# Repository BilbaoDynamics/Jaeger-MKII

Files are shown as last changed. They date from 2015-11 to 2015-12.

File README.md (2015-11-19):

# Jaeger MKII

Jaeger photo

## What's this?

An open source Micro rover robot

## License

GPL license or Creative Commons Attribution-shareAlike (Copyleft)

![license] (http://es.creativecommons.org/blog/wp-content/uploads/2013/04/by-sa_petit.png)

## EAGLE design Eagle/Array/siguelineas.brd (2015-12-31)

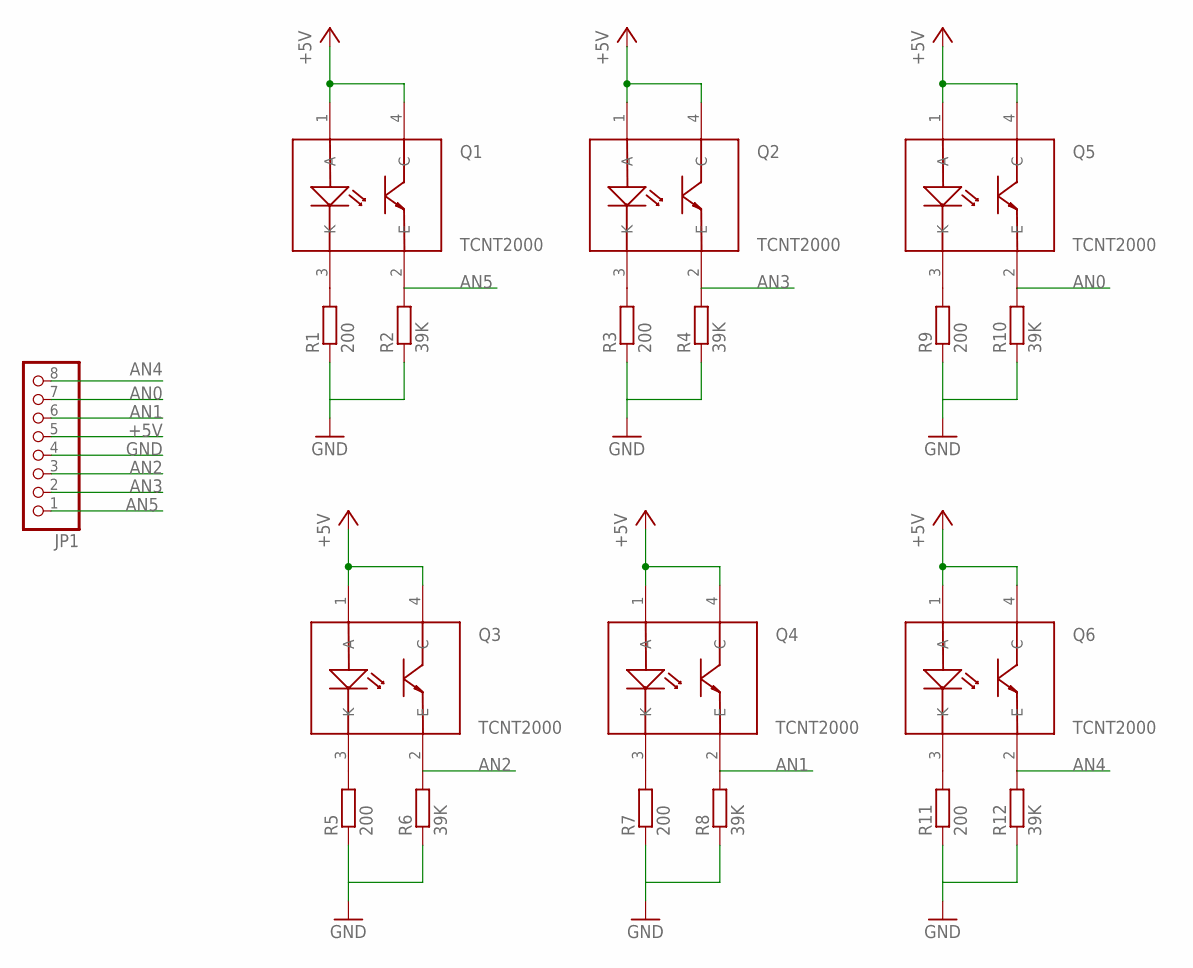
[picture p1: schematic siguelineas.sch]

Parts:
JP1: PINHD-1X8; 1X08
Q1, Q2, Q3, Q4, Q5, Q6: TCNT2000; SMD
R1, R3, R5, R7, R9, R11: 200; R0805
R2, R4, R6, R8, R10, R12: 39K; R0805

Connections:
+5V: JP1.5, Q1.1 (A), Q1.4 (C), Q2.1 (A), Q2.4 (C), Q3.1 (A), Q3.4 (C), Q4.1 (A), Q4.4 (C), Q5.1 (A), Q5.4 (C), Q6.1 (A), Q6.4 (C)
AN0: JP1.7, Q5.2 (E), R10.2
AN1: JP1.6, Q4.2 (E), R8.2
AN2: JP1.3, Q3.2 (E), R6.2
AN3: JP1.2, Q2.2 (E), R4.2
AN4: JP1.8, Q6.2 (E), R12.2
AN5: JP1.1, Q1.2 (E), R2.2
GND: JP1.4, R1.1, R2.1, R3.1, R4.1, R5.1, R6.1, R7.1, R8.1, R9.1, R10.1, R11.1, R12.1
unnamed: Q1.3 (K), R1.2
unnamed: Q2.3 (K), R3.2
unnamed: Q3.3 (K), R5.2
unnamed: Q4.3 (K), R7.2
unnamed: Q5.3 (K), R9.2
unnamed: Q6.3 (K), R11.2

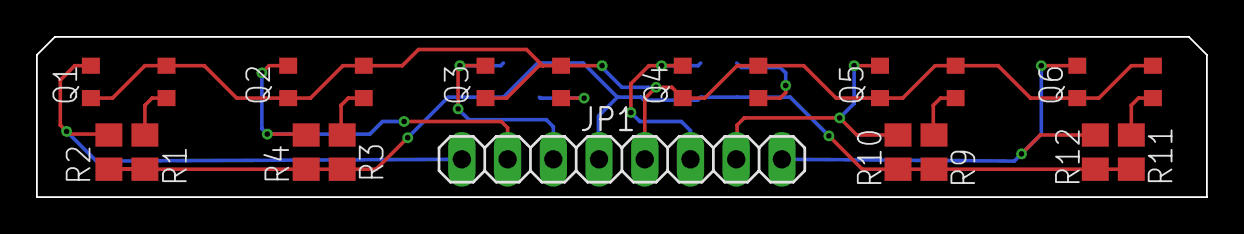
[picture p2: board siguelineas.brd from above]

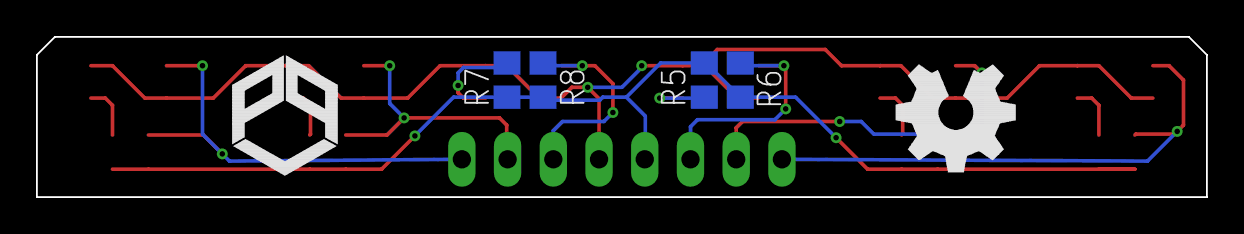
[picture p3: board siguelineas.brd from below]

Board: 2 copper layers, 65.0 x 8.9 mm, 19 parts (4 on the bottom side), 14 nets.

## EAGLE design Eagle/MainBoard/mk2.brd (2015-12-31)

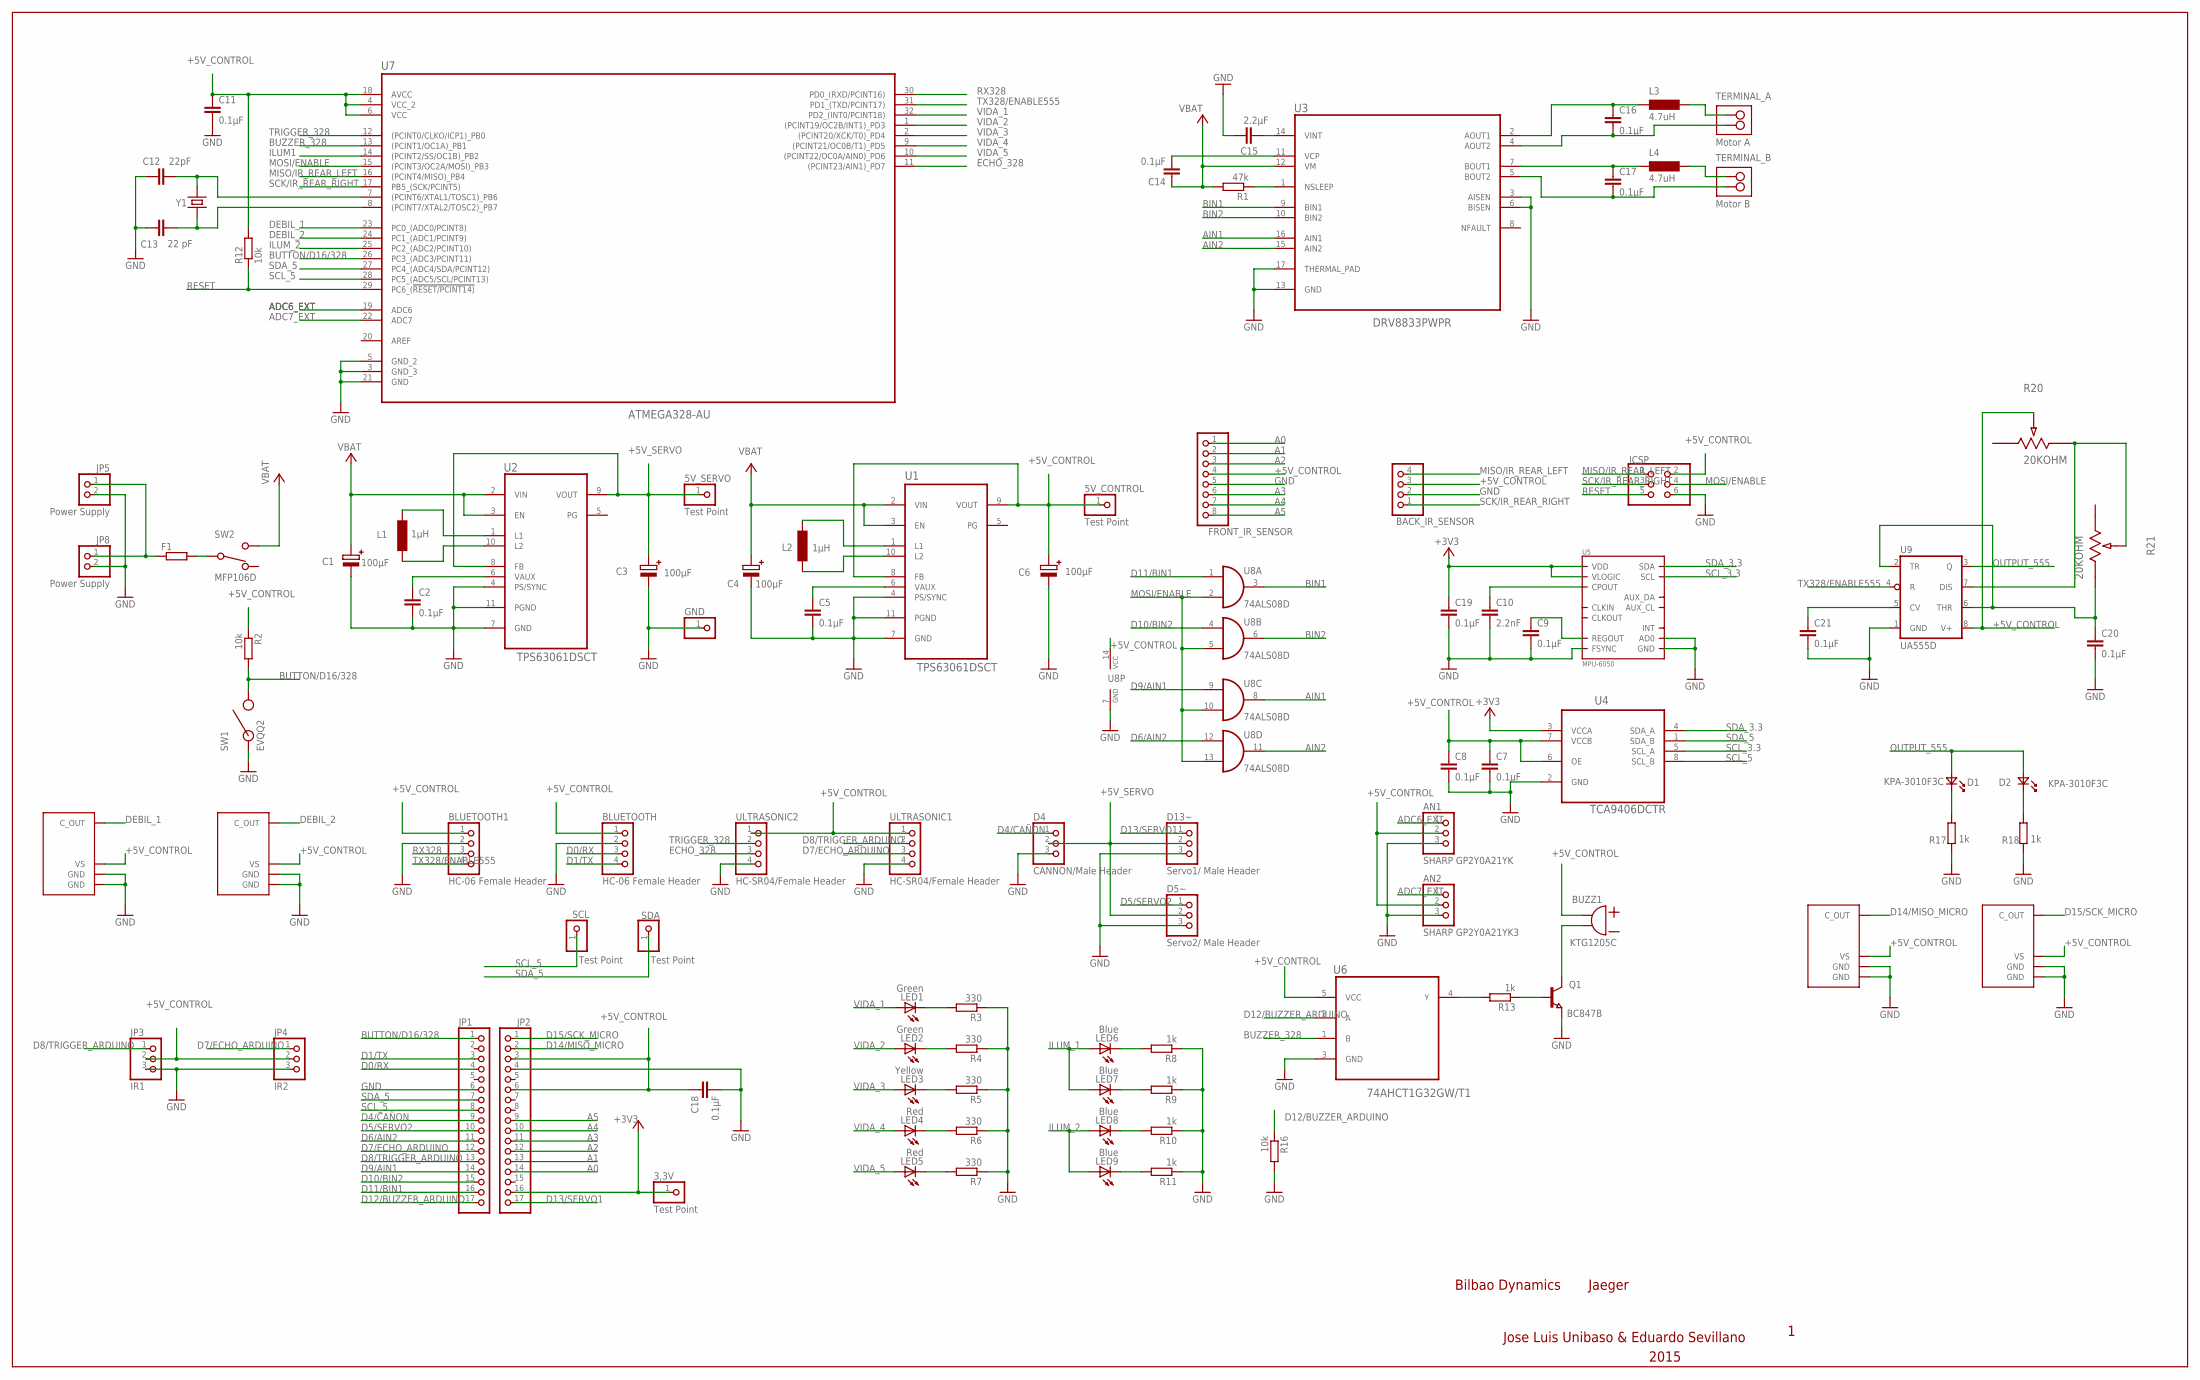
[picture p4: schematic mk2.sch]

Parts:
3,3V, 5V_CONTROL, 5V_SERVO: Test Point; 1X01
AN1: SHARP GP2Y0A21YK; 1X03
AN2: SHARP GP2Y0A21YK3; 1X03
BACK_IR_SENSOR: PINHD-1X4; 1X04
BLUETOOTH, BLUETOOTH1: HC-06 Female Header; 1X04
BUZZ1: KTG1205C
C1, C3, C4, C6: 100µF; EDK107M016A9G
C2, C5, C11: 0.1µF; C0805K
C7, C8, C9, C14, C16, C17, C18, C19, C20, C21: 0.1µF; C0805
C10: 2.2nF; C0805
C12: 22pF; C0805K
C13: 22 pF; C0805K
C15: 2.2µF; C0805
D1, D2: KPA-3010F3C
D4: CANNON/Male Header; 1X03
D5~: Servo2/ Male Header; 1X03
D13~: Servo1/ Male Header; 1X03
F1: R-EU_R1206; R1206
FRONT_IR_SENSOR: PINHD-1X8; 1X08
GND: PINHD-1X1; 1X01
ICSP: PINHD-2X3; 2X03
IR_REC1, IR_REC2, IR_REC3, IR_REC4: TSMP77000TR
JP1, JP2: PINHD-1X17; 1X17
JP3: IR1; 1X03
JP4: IR2; 1X03
JP5, JP8: Power Supply; 1X02
L1, L2: 1µH; MCSDRH73B
L3, L4: 4.7uH; SRN4012T-4R7M
LED1, LED2: Green; SML0805
LED3: Yellow; SML0805
LED4, LED5: Red; SML0805
LED6, LED7, LED8, LED9: Blue; SML0805
Q1: BC847B; SOT23
R1: 47k; R0805
R2, R12, R16: 10k; R0805
R3, R4, R5, R6, R7: 330; R0805
R8, R9, R10, R11, R13, R17, R18: 1k; R0805
R20, R21: 20KOHM; POT_EVM2N
SCL: Test Point; 1X01
SDA: Test Point; 1X01
SW1: EVQQ2
SW2: MFP106D
TERMINAL_A: Motor A; CTB30512BK
TERMINAL_B: Motor B; CTB30512BK
U1, U2: TPS63061DSCT; SON50P300X300X80-11N
U3: DRV8833PWPR; SOP65P640X120-17N
U4: TCA9406DCTR; SOP65P400X130-8N
U5: MPU-6050; QFN.24.4X4
U6: 74AHCT1G32GW/T1; SOT65P210X110-5N
U7: ATMEGA328-AU; QFP80P900X900X120-32N
U8: 74ALS08D; SO14
U9: UA555D; SO08
ULTRASONIC1, ULTRASONIC2: HC-SR04/Female Header; 1X04
Y1: E3SB16.0000F09G11AE; E3SB16.0000F09G11A

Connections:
+3V3: 3,3V.1, JP2.16, U4.3 (VCCA)
+5V_CONTROL: 5V_CONTROL.1, AN1.2, AN2.2, BACK_IR_SENSOR.3, BLUETOOTH.1, BLUETOOTH1.1, BUZZ1.+, C6.1, C7.1, C8.1, C11.1, C18.1, FRONT_IR_SENSOR.4, ICSP.2, IR_REC1.2 (VS), IR_REC2.2 (VS), IR_REC3.2 (VS), IR_REC4.2 (VS), JP2.3, JP2.6, JP3.2, JP4.2, R2.1, R12.2, R20.2, U1.8 (FB), U1.9 (VOUT), U4.6 (OE), U4.7 (VCCB), U6.5 (VCC), U7.4 (VCC_2), U7.6 (VCC), U7.18 (AVCC), U8.14 (VCC), U9.8 (V+), ULTRASONIC1.1, ULTRASONIC2.1
+5V_SERVO: 5V_SERVO.1, C3.1, D4.2, D5~.2, D13~.2, U2.8 (FB), U2.9 (VOUT)
A0: FRONT_IR_SENSOR.1, JP2.14
A1: FRONT_IR_SENSOR.2, JP2.13
A2: FRONT_IR_SENSOR.3, JP2.12
A3: FRONT_IR_SENSOR.6, JP2.11
A4: FRONT_IR_SENSOR.7, JP2.10
A5: FRONT_IR_SENSOR.8, JP2.9
ADC6_EXT: AN1.1, U7.19 (ADC6)
ADC7_EXT: AN2.1, U7.22 (ADC7)
AIN1: U3.16 (AIN1), U8.8 (O)
AIN2: U3.15 (AIN2), U8.11 (O)
AM1: L3.P$2, TERMINAL_A.1
BIN1: U3.9 (BIN1), U8.3 (O)
BIN2: U3.10 (BIN2), U8.6 (O)
BM1: L4.P$2, TERMINAL_B.1
BUTTON/D16/328: JP1.1, R2.2, SW1.P$1, SW1.P$4, U7.26 (PC3_(ADC3/PCINT11))
BUZZER_328: U6.1 (B), U7.13 ((PCINT1/OC1A)_PB1)
C14: C13.2, U7.8 ((PCINT7/XTAL2/TOSC2)_PB7), Y1.1
D0/RX: BLUETOOTH.3, JP1.4
D1/TX: BLUETOOTH.4, JP1.3
D2: D2.C, R18.1
D4/CAÑON: D4.1, JP1.9
D5/SERVO2: D5~.1, JP1.10
D6/AIN2: JP1.11, U8.12 (I0)
D7/ECHO_ARDUINO: JP1.12, JP4.1, ULTRASONIC1.3
D8/TRIGGER_ARDUINO: JP1.13, JP3.1, ULTRASONIC1.2
D9/AIN1: JP1.14, U8.9 (I0)
D10/BIN2: JP1.15, U8.4 (I0)
D11/BIN1: JP1.16, U8.1 (I0)
D12/BUZZER_ARDUINO: JP1.17, R16.1, U6.2 (A)
D13/SERVO1: D13~.1, JP2.17
D14/MISO_MICRO: IR_REC1.3 (C_OUT), JP2.2
D15/SCK_MICRO: IR_REC2.3 (C_OUT), JP2.1
DEBIL_1: IR_REC3.3 (C_OUT), U7.23 (PC0_(ADC0/PCINT8))
DEBIL_2: IR_REC4.3 (C_OUT), U7.24 (PC1_(ADC1/PCINT9))
ECHO_328: U7.11 ((PCINT23/AIN1)_PD7), ULTRASONIC2.3
GND: AN1.3, AN2.3, BACK_IR_SENSOR.2, BLUETOOTH.2, BLUETOOTH1.2, C1.2, C2.2, C3.2, C4.2, C5.2, C6.2, C7.2, C8.2, C9.2, C10.2, C11.2, C12.1, C13.1, C15.1, C18.2, C19.2, C20.2, C21.2, D4.3, D5~.3, D13~.3, FRONT_IR_SENSOR.5, GND.1, ICSP.6, IR_REC1.1 (GND), IR_REC1.4 (GND), IR_REC2.1 (GND), IR_REC2.4 (GND), IR_REC3.1 (GND), IR_REC3.4 (GND), IR_REC4.1 (GND), IR_REC4.4 (GND), JP1.6, JP2.4, JP3.3, JP4.3, JP5.2, JP8.2, Q1.2 (E), R3.1, R4.1, R5.1, R6.1, R7.1, R8.1, R9.1, R10.1, R11.1, R16.2, R17.2, R18.2, SW1.P$2, SW1.P$3, U1.4 (PS/SYNC), U1.7 (GND), U1.11 (PGND), U2.4 (PS/SYNC), U2.7 (GND), U2.11 (PGND), U3.3 (AISEN), U3.6 (BISEN), U3.13 (GND), U3.17 (THERMAL_PAD), U4.2 (GND), U5.9 (AD0), U5.11 (FSYNC), U5.18 (GND), U6.3 (GND), U7.3 (GND_3), U7.5 (GND_2), U7.21 (GND), U8.7 (GND), U9.1 (GND), ULTRASONIC1.4, ULTRASONIC2.4
ILUM1: U7.14 ((PCINT2/SS/OC1B)_PB2)
ILUM_1: LED6.A, LED7.A
ILUM_2: LED8.A, LED9.A, U7.25 (PC2_(ADC2/PCINT10))
LED4: LED4.C, R6.2
MISO/IR_REAR_LEFT: BACK_IR_SENSOR.4, ICSP.1, U7.16 ((PCINT4/MISO)_PB4)
MOSI/ENABLE: ICSP.4, U7.15 ((PCINT3/OC2A/MOSI)_PB3), U8.2 (I1), U8.5 (I1), U8.10 (I1), U8.13 (I1)
unnamed: C16.1, L3.P$1, U3.2 (AOUT1)
unnamed: C16.2, TERMINAL_A.2, U3.4 (AOUT2)
unnamed: C17.1, L4.P$1, U3.7 (BOUT1)
unnamed: C17.2, TERMINAL_B.2, U3.5 (BOUT2)
unnamed: C19.1, U5.8 (VLOGIC), U5.13 (VDD)
unnamed: F1.1, JP5.1, JP8.1
unnamed: R1.1, U3.1 (NSLEEP)
unnamed: C14.2, U3.11 (VCP)
unnamed: L2.2, U1.1 (L1)
unnamed: C2.1, U2.6 (VAUX)
unnamed: L2.1, U1.10 (L2)
unnamed: R13.2, U6.4 (Y)
unnamed: Q1.1 (B), R13.1
unnamed: L1.2, U2.1 (L1)
unnamed: L1.1, U2.10 (L2)
unnamed: BUZZ1.-, Q1.3 (C)
unnamed: C5.1, U1.6 (VAUX)
unnamed: LED1.C, R3.2
unnamed: LED2.C, R4.2
unnamed: LED3.C, R5.2
unnamed: LED8.C, R10.2
unnamed: D1.C, R17.1
unnamed: LED5.C, R7.2
unnamed: C15.2, U3.14 (VINT)
unnamed: C12.2, U7.7 ((PCINT6/XTAL1/TOSC1)_PB6), Y1.2
unnamed: C20.1, R21.3, U9.2 (TR), U9.6 (THR)
unnamed: LED6.C, R8.2
unnamed: LED7.C, R9.2
unnamed: LED9.C, R11.2
unnamed: C10.1, U5.20 (CPOUT)
unnamed: C9.1, U5.10 (REGOUT)
unnamed: R20.3, R21.2, U9.7 (DIS)
unnamed: F1.2, SW2.COM
unnamed: C21.1, U9.5 (CV)
OUTPUT_555: D1.A, D2.A, U9.3 (Q)
RESET: ICSP.5, R12.1, U7.29 (PC6_(!RESET/PCINT14))
RX328: BLUETOOTH1.3, U7.30 (PD0_(RXD/PCINT16))
SCK/IR_REAR_RIGHT: BACK_IR_SENSOR.1, ICSP.3, U7.17 (PB5_(SCK/PCINT5))
SCL_3.3: U4.5 (SCL_A), U5.23 (SCL)
SCL_5: JP1.8, SCL.1, U4.8 (SCL_B), U7.28 (PC5_(ADC5/SCL/PCINT13))
SDA_3.3: U4.4 (SDA_A), U5.24 (SDA)
SDA_5: JP1.7, SDA.1, U4.1 (SDA_B), U7.27 (PC4_(ADC4/SDA/PCINT12))
TRIGGER_328: U7.12 ((PCINT0/CLKO/ICP1)_PB0), ULTRASONIC2.2
TX328/ENABLE555: BLUETOOTH1.4, U7.31 (PD1_(TXD/PCINT17)), U9.4 (R)
VBAT: C1.1, C4.1, C14.1, R1.2, SW2.2, U1.2 (VIN), U1.3 (EN), U2.2 (VIN), U2.3 (EN), U3.12 (VM)
VIDA_1: LED1.A, U7.32 (PD2_(INT0/PCINT18))
VIDA_2: LED2.A, U7.1 ((PCINT19/OC2B/INT1)_PD3)
VIDA_3: LED3.A, U7.2 ((PCINT20/XCK/T0)_PD4)
VIDA_4: LED4.A, U7.9 ((PCINT21/OC0B/T1)_PD5)
VIDA_5: LED5.A, U7.10 ((PCINT22/OC0A/AIN0)_PD6)

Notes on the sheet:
Bilbao Dynamics
Jaeger
Jose Luis Unibaso & Eduardo Sevillano
2015

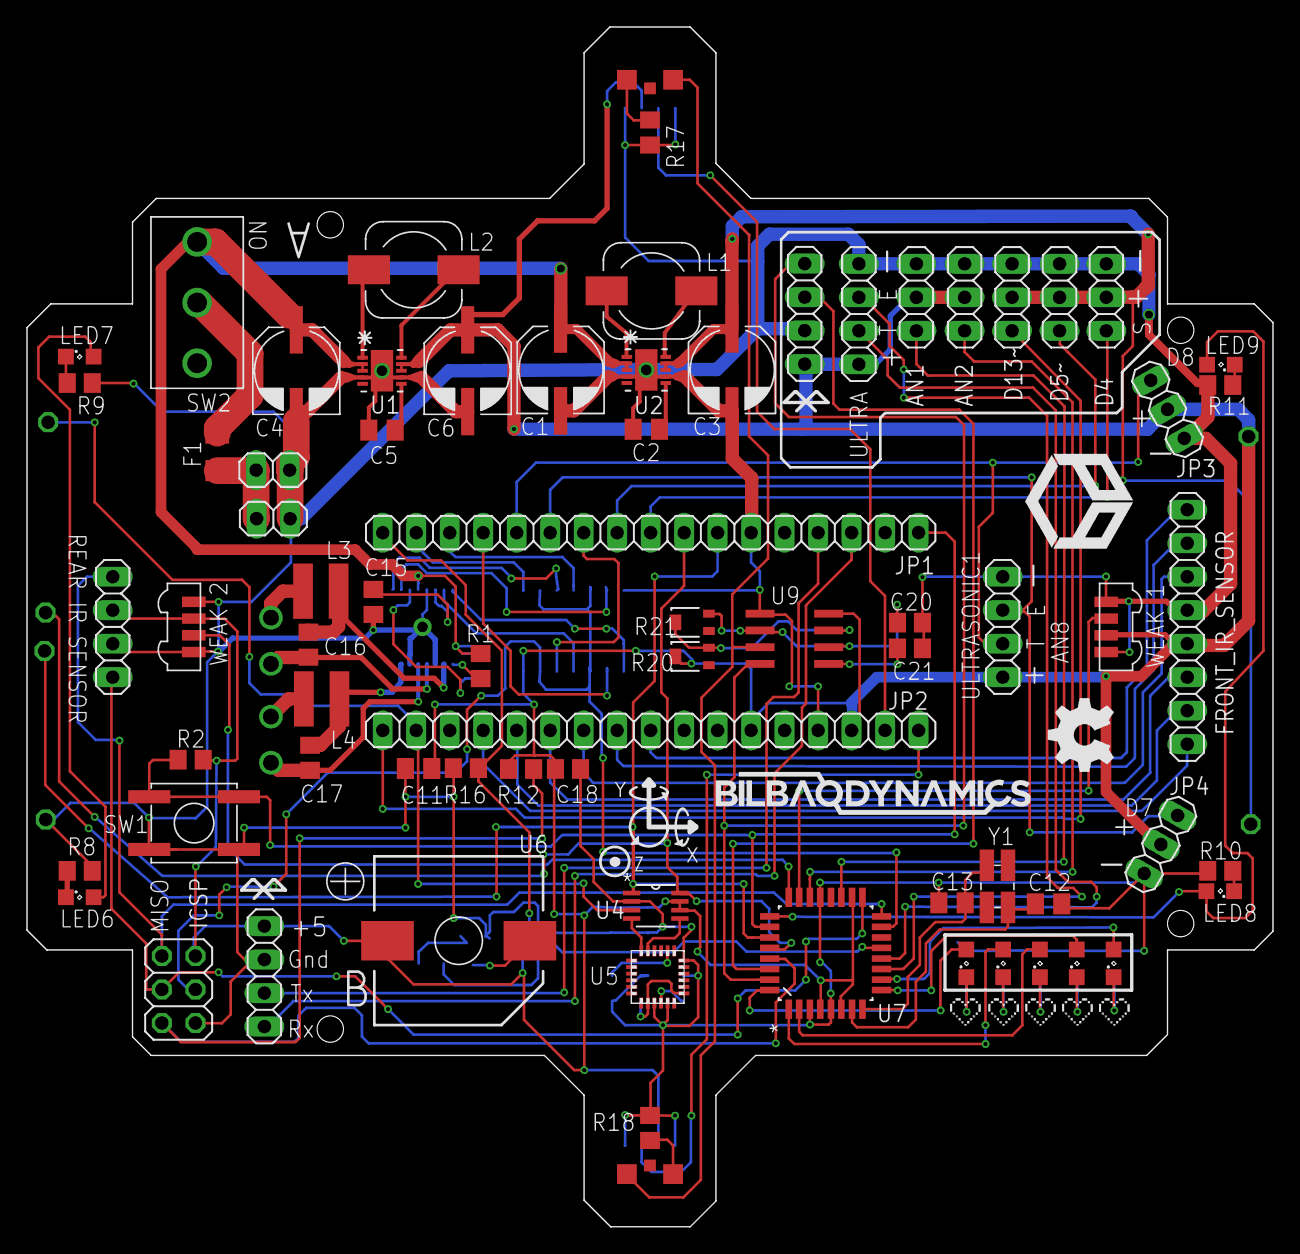
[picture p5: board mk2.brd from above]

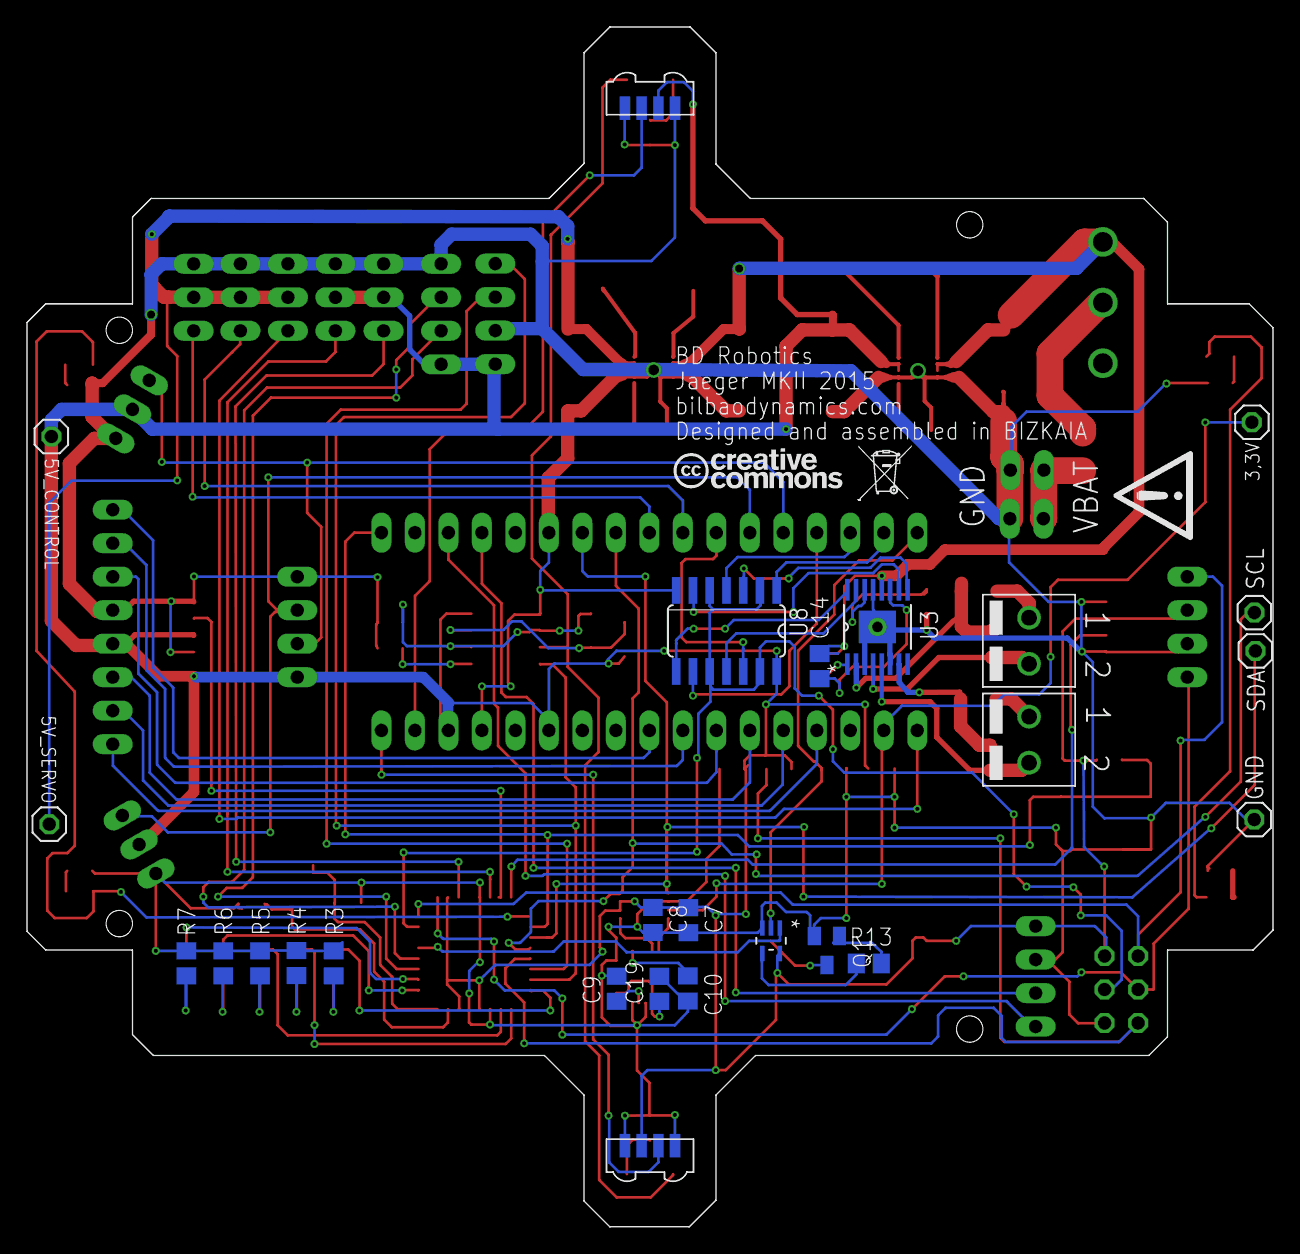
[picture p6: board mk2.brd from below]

Board: 2 copper layers, 94.5 x 91.0 mm, 99 parts (24 on the bottom side), 94 nets.

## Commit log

2015-11-17 Eagle Folder
    [mk2.brd, mk2.sch, siguelineas.brd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]
2015-11-18 File Update
    [mk2.brd]
2015-12-17 update
    files
    [mk2.brd, mk2.sch, siguelineas.brd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]
